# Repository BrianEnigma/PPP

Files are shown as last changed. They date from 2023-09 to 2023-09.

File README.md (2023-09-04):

# The Poltergeist Piano Project (PPP)

## Overview

I'm friends with the owners of a local spooky bar. It's not just a great bar with gourmet food, there's a lot of depth to explore. They've rigged up a bunch of fun gadgetry. There's a mini escape room where dialing a particular phone number plays a prerecorded message and pops open a secret door. There's creepy audio in one of the bathrooms. There's a painting on the wall that jumps out at you as you pass by. There's thunder and lightning in the windows and a flickering fireplace.

One of the owners pointed me to [a YouTube video](https://youtu.be/S7Bd992k368?si=S3JPkRpDpxUU6mec) of a guy who turned his upright piano into a player piano. They have a piano there that people poke at as they pass by to get to the bathroom. He wanted to do something like that to their piano. Turning it into a full player piano was probably out of the question, given time, materials, and tediousness of wiring up each and every one of the 88 keys. But there was definitely a nugget of an idea there.

I proposed a smaller-scale animatronic solution that aligned better with the spooky nature of the bar:

- Three individual low keys wired up.
- A trill (or stinger) of several high keys connected together, to give a bit of a bang-on-the-keys jump scare.
- Some lighting to better draw attention that something's about to happen (and IS happening).
- A distance/proximity sensor to trigger the animation when someone is close-by.
- Tie it all together with a microcontroller that not only controlls all aspects of triggering, animtion, and piano key action, but can also provide holdoff timers so that it doesn't get triggered too terribly often (to the annoyance of bar staff).

## Documentation

[Documentation Here](./Docs)

## License

This project was a commission for a local spooky bar. I am releasing the design files for personal/private/educational use under a [Creative Commons Attribution-NonCommercial-ShareAlike 4.0 International license](https://creativecommons.org/licenses/by-nc-sa/4.0/). You're free to use this project as-is or mutate it into something else if and only if it's for private use in your own home.

If you'd like to use these designs in a public or commercial setting, such as a bar or restaurant, please reach out to me to work out a more specific commercial arrangement.

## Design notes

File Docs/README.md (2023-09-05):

# Poltergeist Piano Project

## Overview

Please read [the top-level readme file](../) for the descriptive overview of this project.

## Bill of Materials (BOM)

- [Adafruit Feather Huzzah, ESP8266](https://www.adafruit.com/product/2821)
    - A similar microcontroller can be used. I just happen to have a ton of these on hand because they're versatile and relatively cheap. This one happens to have a WiFi chip on board, but it's entirely dormant for this project.
- [128x64 OLED screen for Feather](https://www.adafruit.com/product/4650)
    - 100% optional. I like it because it gives me a status display and three buttons that can be used for testing.
- [12V Solenoid](https://www.adafruit.com/product/413) × 4
- [IR Distance Sensor](https://www.adafruit.com/product/1031)
- [Neopixel Strip](https://www.adafruit.com/product/1460), about 53 inches to span the piano
- TIP120 Darlington Transistors × 4
- 1N4004 Diodes × 4
- 1K Ω Resistors × 4
- [7805 5V Linear Voltage Regulator](https://www.adafruit.com/product/2164)
- 12VDC power supply and inline power switch.
- Assorted miscellanea. Wires, solder, heat-shrink tubing, terminal blocks, etc.

## Schematic

The [schematic (pdf link)](schematic.pdf) is fairly straightforward. The [KiCad](https://www.kicad.org) source lives in [the KiCad project folder](../KiCad/). Each of the solenoids is a copy/paste job, joining together a power transistor, resistor, diode, and the solenoid. The Neopixel is wired to a binary data pin. The distance sensor is wired to the one and only ADC pin.

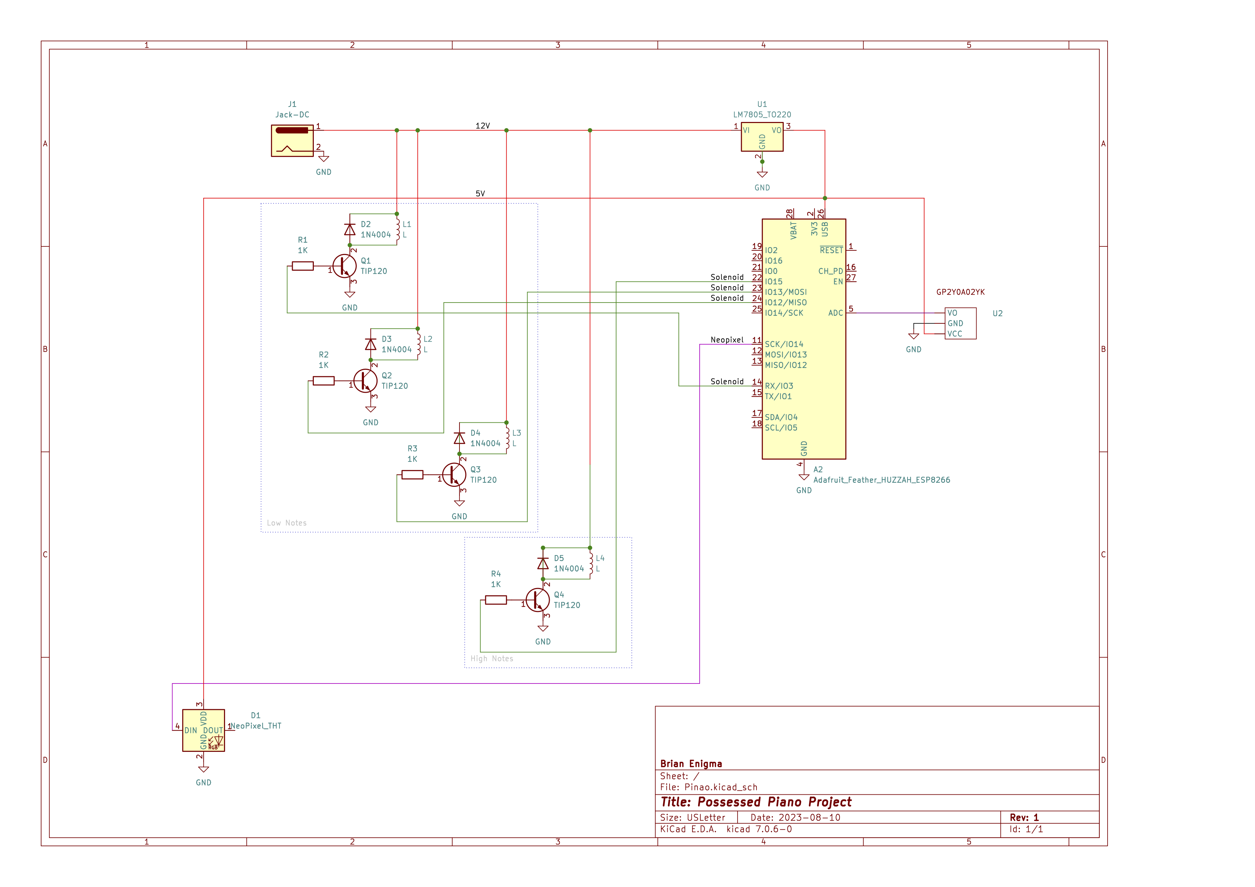
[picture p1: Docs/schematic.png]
schematic


It's worth noting that the pin number that KiCan assigns to the Feather Huzzah microcontroller are not intuitive. They don't match the pin numbers silk-screened onto the board. Nor do they match the internal pin numbers of the ESP8266:

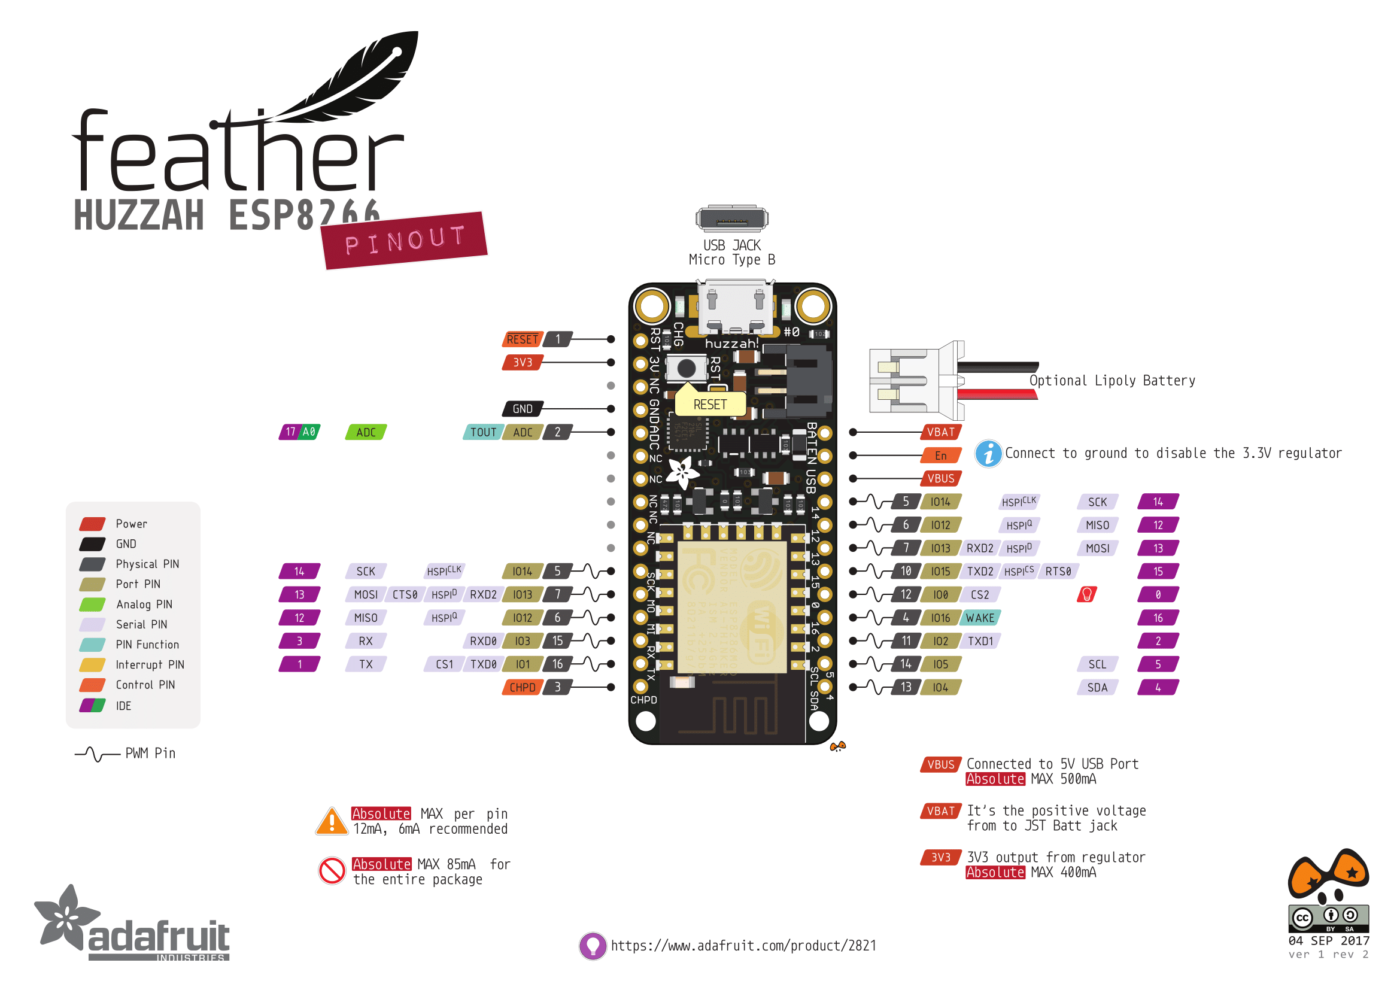
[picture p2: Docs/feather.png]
Feather Huzzah


The numbers in KiCad, instead, count around the outside of the board, treating it like a regular IC chip. For example, looking at the above pinout, KiCad labels “pin 1” as the reset, “pin 2” is the 3.3V line, “pin 3” is the not-connected pin, etc.

## Main-Board Assembly

This is a custom layout on a protoboard.

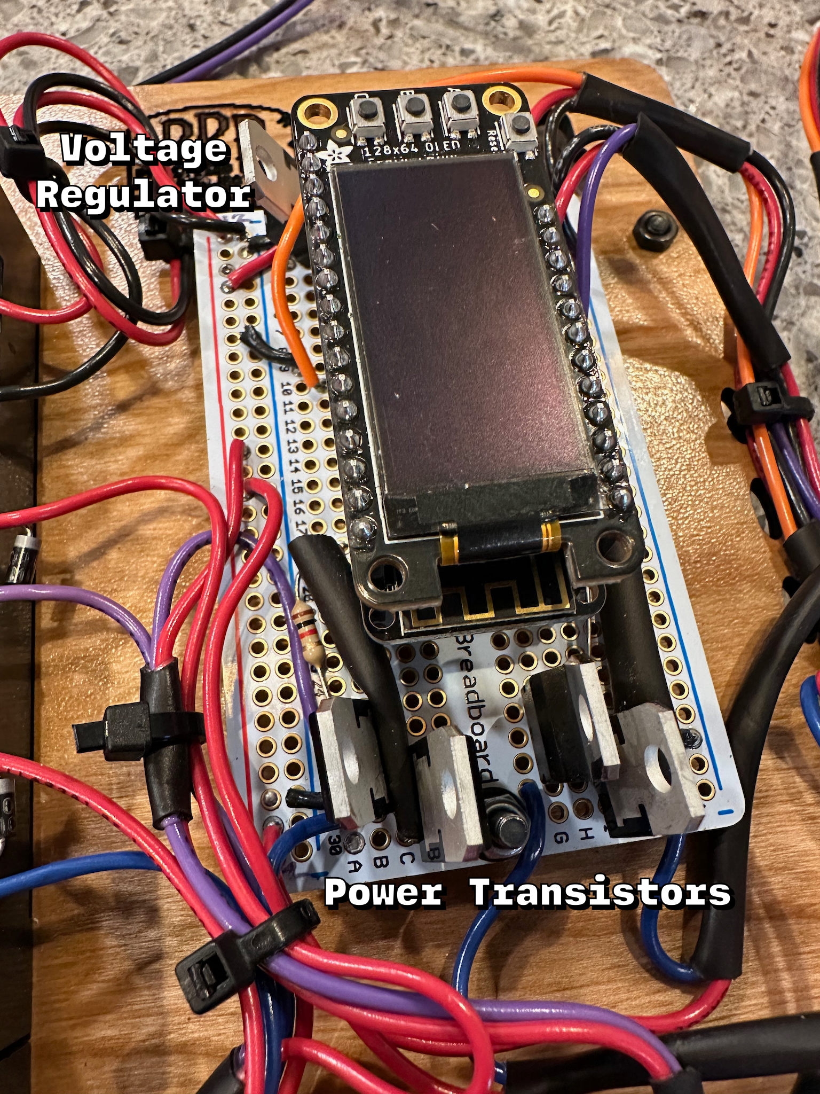
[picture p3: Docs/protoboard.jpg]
protoboard


That protoboard is then attached to a wood backboard that can be mounted. It interfaces with all the remote devices and sensor through screw-down terminal blocks. The lase file for the wood backboard is in [the Laser project folder](../Laser/).

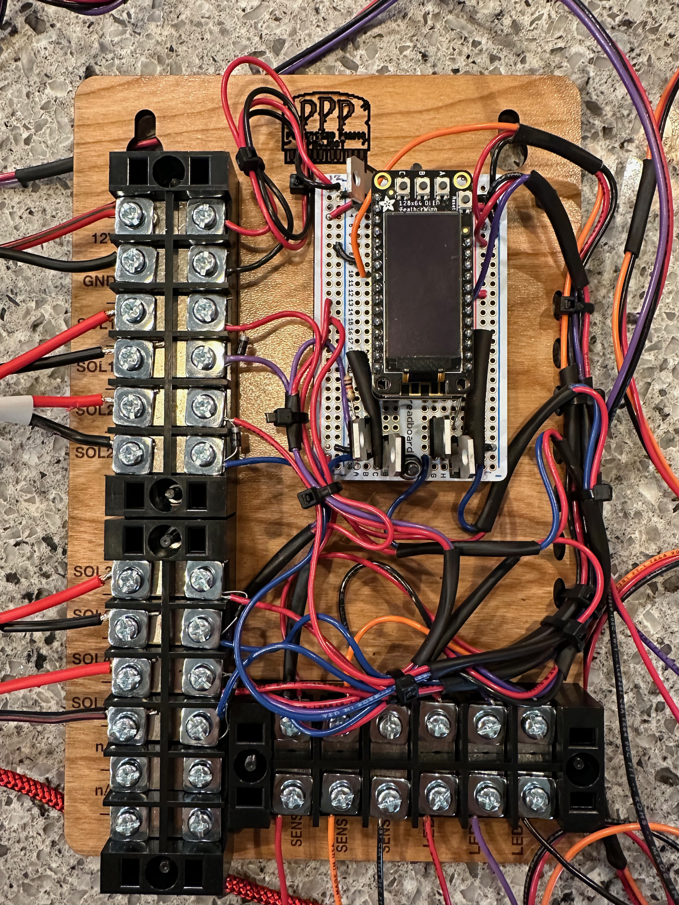
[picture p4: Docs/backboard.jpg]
backboard


Both the Feather microcontroller and the OLED carrier board are attached via pin socket. Either/or can be easily replaced without needing to solder.

## Device/Sensor Assembly

- The solenoids are basic — there are two wires and, because they are simply electromagnetic coils, they are not polarized. They are physically labeled on the solenoid, the hookup wire, and the terminal blocks (as well as in code) 1..4:
    - Solenoid 1: low note
    - Solenoid 2: lower note
    - Solenoid 3: lowest note
    - Solenoid 4: high trill/stinger
- The Neeopixel strip has power, ground, and a data line.
- The proximity/distance sensor has power, ground, and an analog sense line.
- The power plug supplies 12VDC to the mainboard, which gets divided into a 12VDC rail and a 5VDC rail.

All are wired into the labeled terminal blocks. The terminal blocks for the solenoids, on the mainboard side, have protective diodes screwed in along side the hookup wires.

The solenoids are mounted into 3D-printed brackets. These are printed in ABS (the same plastic as LEGO bricks) for strength. They are attached by 6mm M3 metric screws. The bracket files can be found in [the Brackets project folder](../Brackets/).

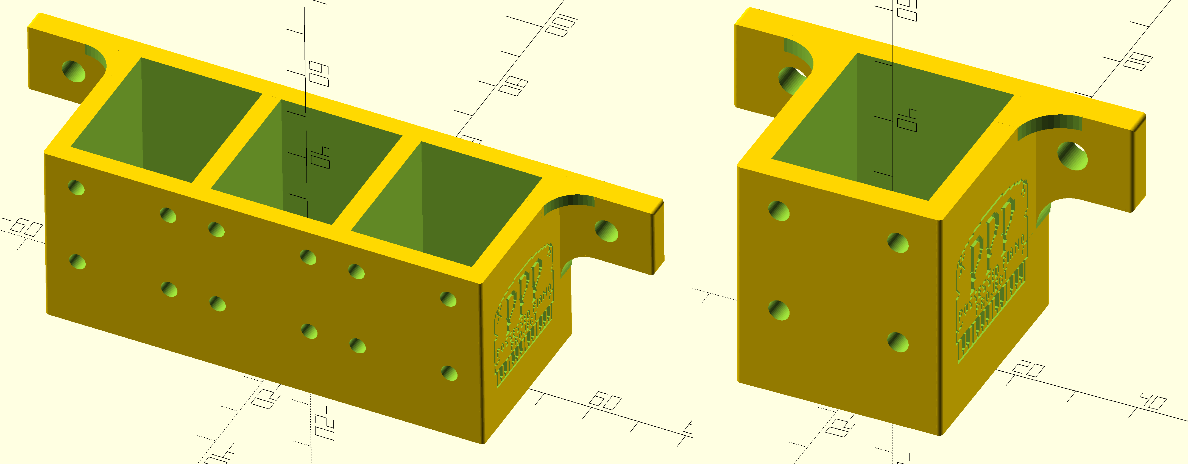
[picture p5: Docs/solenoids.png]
solenoid brackets


_(The above two solenoid images are not to scale between each other. Every cubbyhole is for the same size solenoid.)_

The power plug mount is also printed in ABS and lives in that same folder.

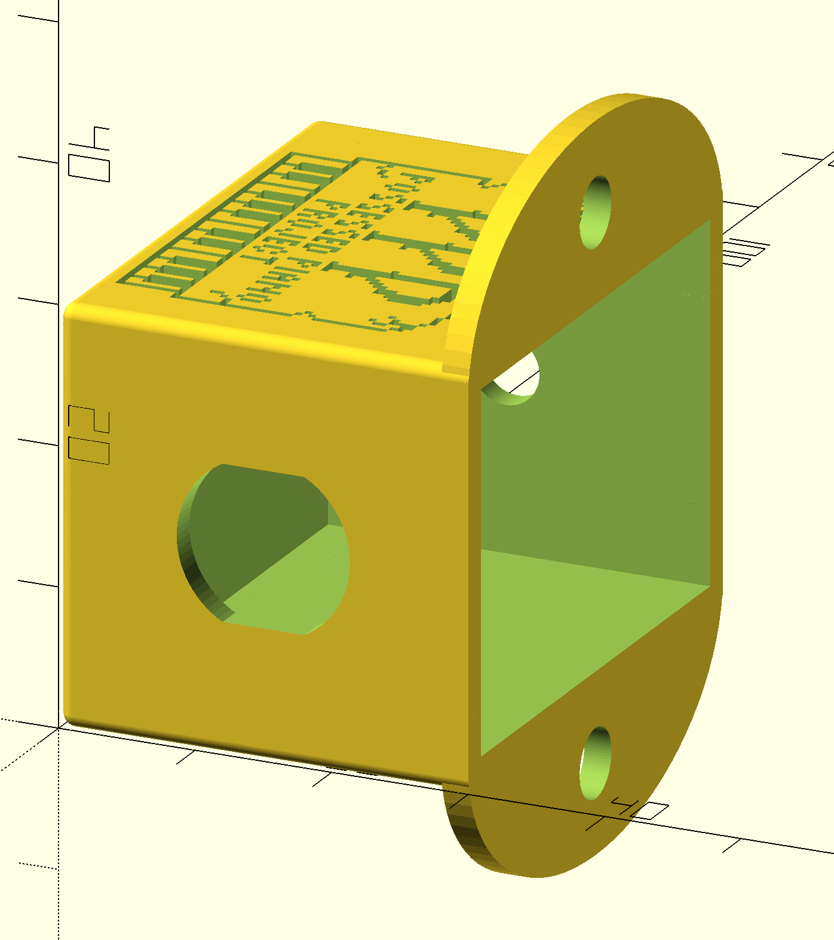
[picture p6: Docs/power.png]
power bracket


## Test Code

There are assorted test/bringup code projects in [the Bringup project folder](../Bringup/). These were used during hardware development and assembly to test out individual circuits and components.

## Production Code

### IDE Setup / Prerequisites

Code is compiled and uploaded through the Arduino IDE. [This can be downloaded from the Arduino site](https://www.arduino.cc/en/software) for Windows, macOS, or Linux. Once the IDE is installed, you'll have to launch it and use its features to install the dependencies required for the microcontroller, display, and LED strip. Adafruit has great guides for installation:

- [Feather Huzzah ESP 8266 toolchain](https://learn.adafruit.com/adafruit-feather-huzzah-esp8266/using-arduino-ide)
- [OLED board library](https://learn.adafruit.com/adafruit-128x64-oled-featherwing/arduino-code)
- [Neopixel library](https://learn.adafruit.com/adafruit-neopixel-uberguide/arduino-library-installation)

New code is uploaded through the micro USB port on the Feather board (it's the board behind the board carrying the OLED screen). Connecting can be a little tight because of the mounting screw for the white protoboard. But there's some give here because the microcontroller is in a socket and can be lifted up slightly.

### The Code

The code performs the following operations:

- At power-up, accidentally, one of the low piano key solenoids is briefly activated. This is a hardware accident (see bugs).
- A holdoff timer of 10 seconds (`POST_BOOT_HOLDOFF_TIMER`) starts counting down. This lets you be near the piano without immediately triggering the animation. Like in _Alien,_ this is a “minimum time to reach safe distance.” This can be bypassed with the “A” button on the display board.
- It waits for the proximity sensor to trigger. The trigger point is `ANALOG_THRESHOLD`, but the sensor I used is a little far-sighted. It's basically either “you're really far away” or “holy crap, you're within 3 feet.” So this threshold is a little bit meaningless.
- Once it detects someone is nearby, it:
    - There's a 1-in-10 (`HIGH_HIT_RANDOM`) chance of triggering the short single-flash, single-high-key-slam animation.
    - Otherwise it triggers the three low key animation.
- It enters a holdoff timer that lasts a random number of minutes between 25 (`HOLDOFF_MIN_TIME_MINUTES`) and 45 (`HOLDOFF_MAX_TIME_MINUTES`).

To help with debugging:

- Any holdoff timer (the power-up one or the between-animations one) can be skipped by hitting the “A” button.
- The between-animations holdoff can also be skipped and immediately go to a specific animation by hitting “C” (low-note animation) or “B” (high-note animation). This allows for testing the hardware installation.

The monospaced name above are constants that can be tweaked in the source and then re-uploaded into the microcontroller.

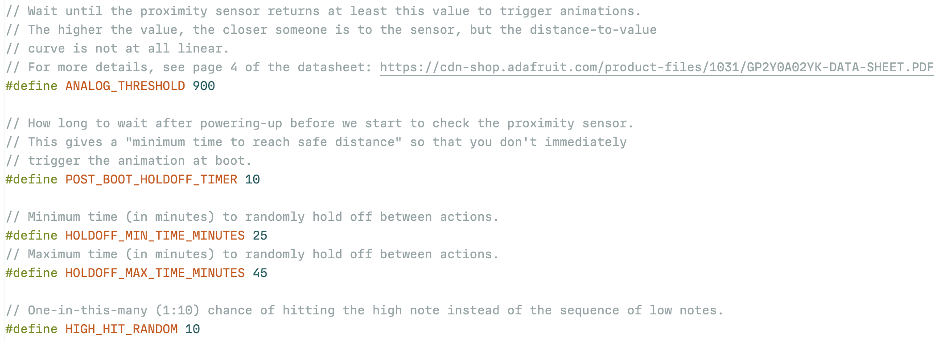
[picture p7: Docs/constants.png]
constants


## Bugs

At power-up, there appears to be a power spike on the Solenoid 1 pin. This appears to be some state the mictrocontroller gets into before any user code is executed. This makes it tough to fix without a big redesign of the circuit. Practically speaking, this means that when powering up the mainboard, one of the low notes gets briefly hit.

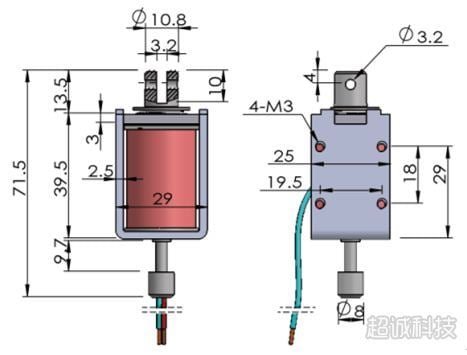
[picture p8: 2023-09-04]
Brackets/large_solenoid_mechanical_schematic.jpg

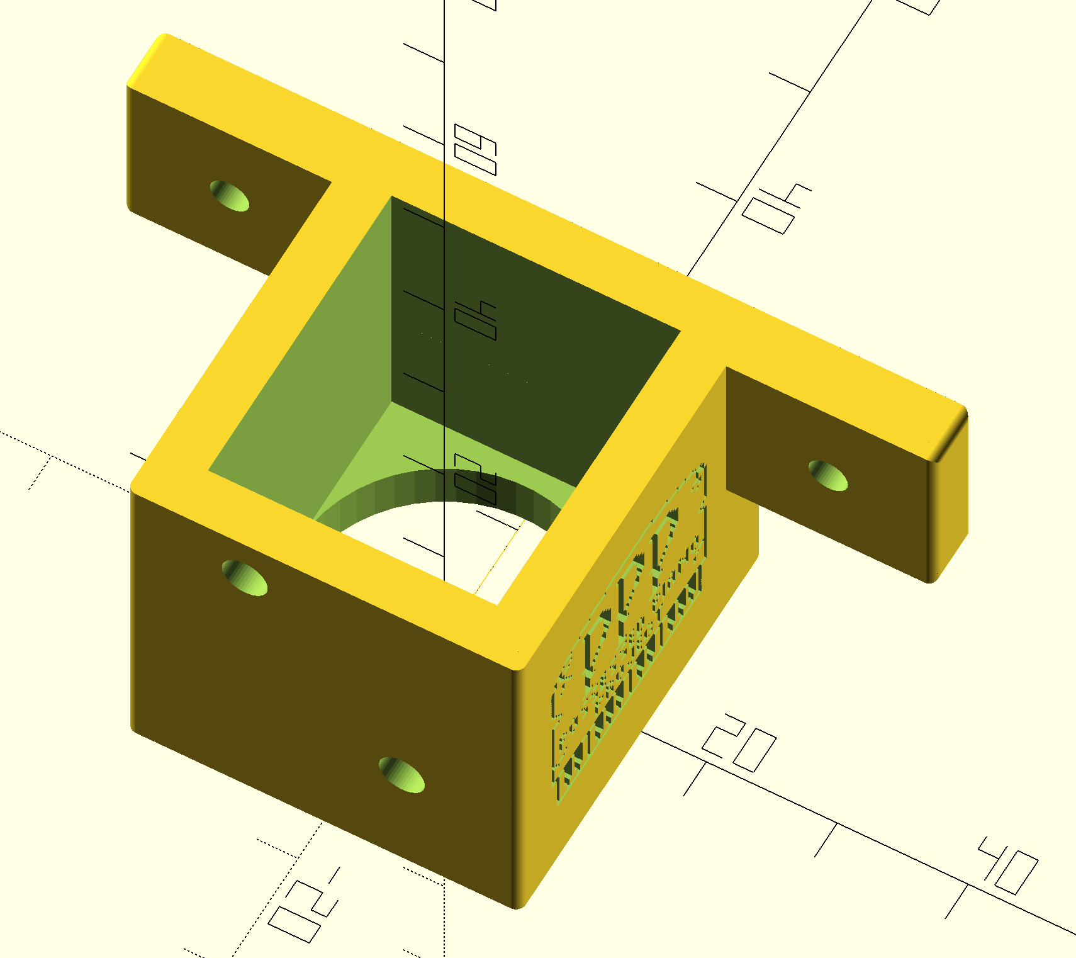
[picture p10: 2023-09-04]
Brackets/small_solenoid_bracket_single-render.png

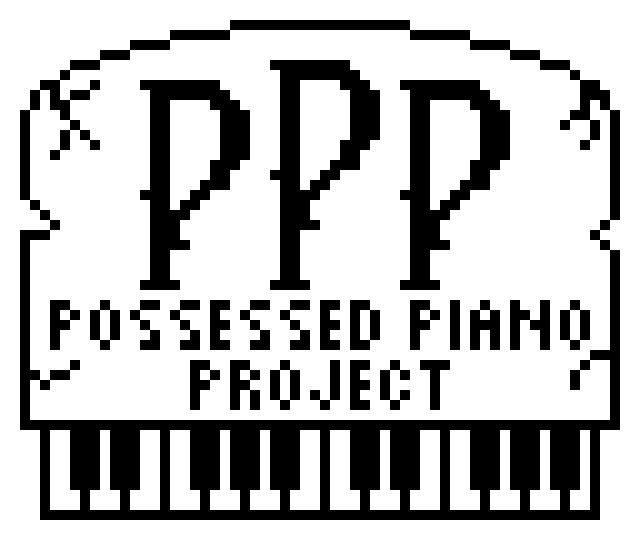
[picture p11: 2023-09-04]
Pixelart/headstone_transparent.png

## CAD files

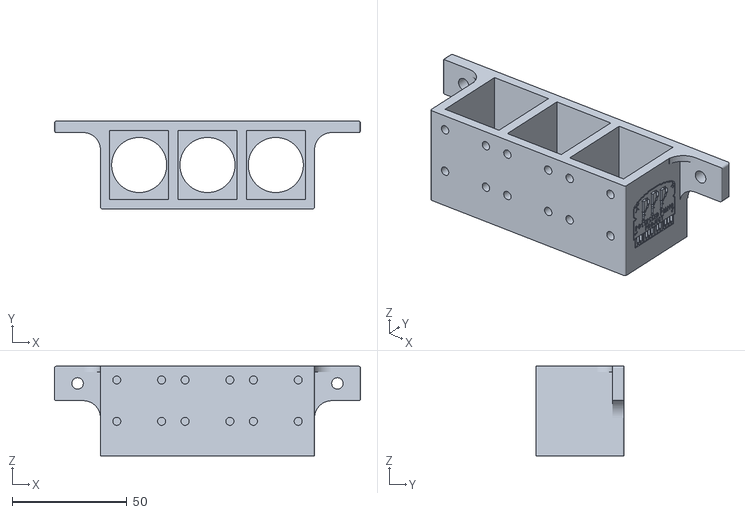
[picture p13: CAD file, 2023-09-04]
Brackets/large_solenoid_bracket_triple.stl
133.2 x 38.2 x 39.0

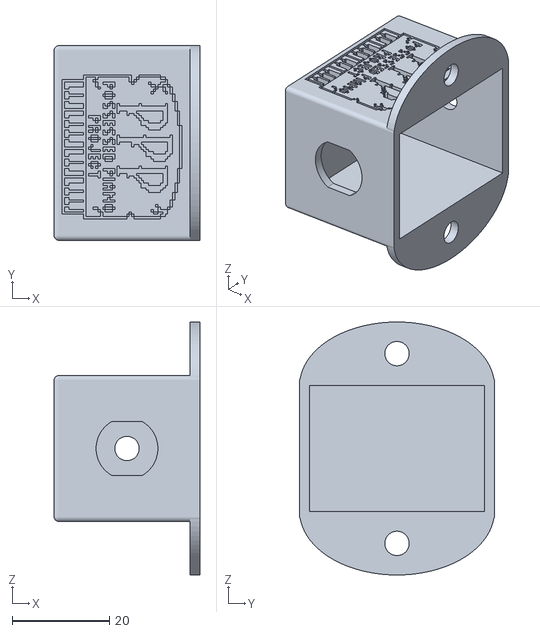
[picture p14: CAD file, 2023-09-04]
Brackets/power_bracket.stl
30.0 x 40.0 x 52.0

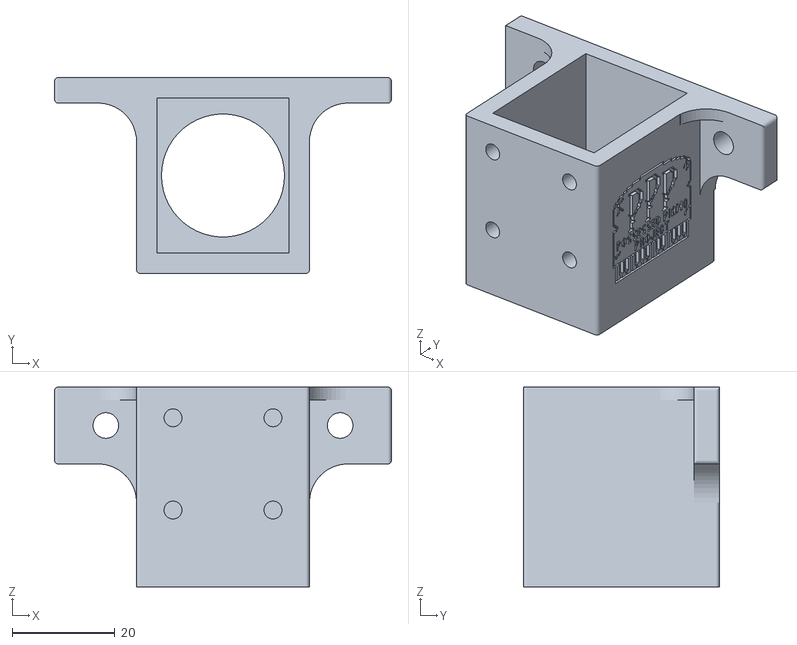
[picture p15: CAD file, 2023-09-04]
Brackets/large_solenoid_bracket_single.stl
65.8 x 38.2 x 39.0

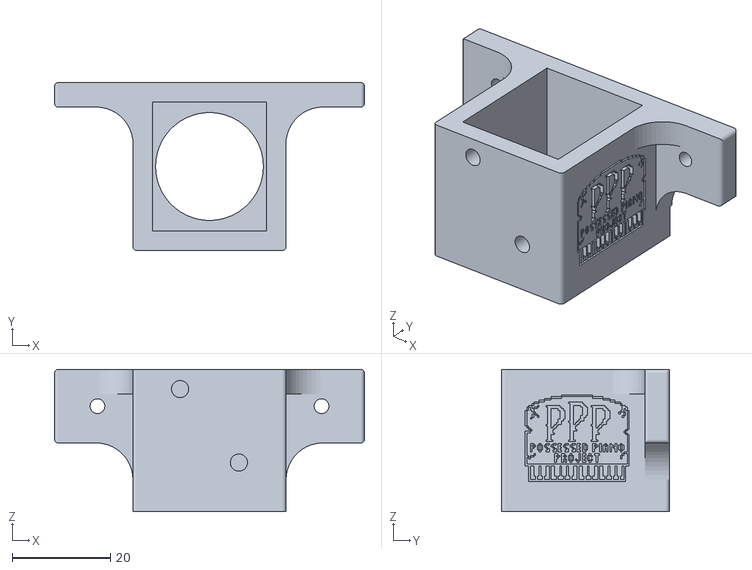
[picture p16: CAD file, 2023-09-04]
Brackets/small_solenoid_bracket_single.stl
63.2 x 34.2 x 29.0

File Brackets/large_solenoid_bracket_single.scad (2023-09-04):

include <BOSL/shapes.scad>
use <BOSL/shapes.scad>

DETAIL = 50;
TOLERANCE = 0.25;
WALL_WIDTH = 4;
FILLET = 0.75;

SOLENOID_WIDTH = 25.5 + TOLERANCE;
SOLENOID_HEIGHT = 30 + TOLERANCE;
SOLENOID_DEPTH = 35;
SOLENOID_OPENING_DIAMETER = 24;

SOLENOID_SCREW_HOLE_OFFSET_X = (19.5 / 2);
SOLENOID_SCREW_HOLE_OFFSET_Y1 = 11;
SOLENOID_SCREW_HOLE_OFFSET_Y2 = 29;
SOLENOID_SCREW_HOLE_DIAMETER = 3.5;

BRACKET_WIDTH = SOLENOID_WIDTH + 40;
BRACKET_HEIGHT = 15;
BRACKET_WALL = 5;
BRAKET_SCREW_HOLE_DIAMETER = 5;

module solenoid_body()
{
        translate(v = [0, 0, SOLENOID_DEPTH / 2 + 5 + WALL_WIDTH])
            cube(size = [SOLENOID_WIDTH, SOLENOID_HEIGHT, SOLENOID_DEPTH + 10], center = true);
}

module screw_hole(offset_x, offset_y)
{
    translate(v = [offset_x, 0, offset_y])
        translate(v = [0, 0, WALL_WIDTH])
            rotate(a = [90, 0, 0])
                cylinder(r = SOLENOID_SCREW_HOLE_DIAMETER / 2, h = SOLENOID_HEIGHT, $fn = DETAIL);

}

module main_body()
{
    body_width = SOLENOID_WIDTH + WALL_WIDTH * 2;
    body_height = SOLENOID_HEIGHT + WALL_WIDTH * 2;
    body_depth = SOLENOID_DEPTH + WALL_WIDTH;
    difference()
    {
        // Main body
        translate(v = [0, 0, body_depth / 2])
            cuboid(
                size = [body_width, body_height, body_depth],
                fillet = FILLET,
                edges = EDGES_Z_ALL,
                center = true,
                $fn = DETAIL
                );

        // Hole for solenoid slug
        translate(v = [0, 0, -1])
            cylinder(r = SOLENOID_OPENING_DIAMETER / 2, h = body_depth + 10, $fn = DETAIL);
        // Solenoid body
        solenoid_body();
        // Mounting holes
        screw_hole(     SOLENOID_SCREW_HOLE_OFFSET_X, SOLENOID_SCREW_HOLE_OFFSET_Y1);
        screw_hole(-1 * SOLENOID_SCREW_HOLE_OFFSET_X, SOLENOID_SCREW_HOLE_OFFSET_Y1);
        screw_hole(     SOLENOID_SCREW_HOLE_OFFSET_X, SOLENOID_SCREW_HOLE_OFFSET_Y2);
        screw_hole(-1 * SOLENOID_SCREW_HOLE_OFFSET_X, SOLENOID_SCREW_HOLE_OFFSET_Y2);
    }
}

module bracket1()
{
    difference()
    {
        // Body
        translate(v = [0, SOLENOID_HEIGHT / 2 + WALL_WIDTH + BRACKET_WALL / -2, BRACKET_HEIGHT / -2 + SOLENOID_DEPTH + WALL_WIDTH])
            cuboid(
                size = [BRACKET_WIDTH, BRACKET_WALL, BRACKET_HEIGHT], 
                fillet = FILLET, 
                edges = EDGES_Z_ALL + EDGES_Y_ALL,
                center = true, 
                $fn = DETAIL);
        // Screw holes
        translate(v = [(BRACKET_WIDTH - SOLENOID_WIDTH) / 1.75, SOLENOID_HEIGHT / 2 - 3, BRACKET_HEIGHT / -2 + SOLENOID_DEPTH + WALL_WIDTH])
            rotate(a = [-90, 0, 0])
                cylinder(r = BRAKET_SCREW_HOLE_DIAMETER / 2, h = BRACKET_WALL * 2, $fn = DETAIL);
        translate(v = [(BRACKET_WIDTH - SOLENOID_WIDTH) / -1.75, SOLENOID_HEIGHT / 2 - 3, BRACKET_HEIGHT / -2 + SOLENOID_DEPTH + WALL_WIDTH])
            rotate(a = [-90, 0, 0])
                cylinder(r = BRAKET_SCREW_HOLE_DIAMETER / 2, h = BRACKET_WALL * 2, $fn = DETAIL);
    }
}

module bracket2()
{
    difference()
    {
        translate(v = [0, SOLENOID_HEIGHT / 2 + WALL_WIDTH + BRACKET_WALL / -2, BRACKET_HEIGHT / -4 + SOLENOID_DEPTH + WALL_WIDTH - BRACKET_HEIGHT + 0.01])
            cuboid(
                size = [SOLENOID_WIDTH + WALL_WIDTH * 2 + BRACKET_HEIGHT, BRACKET_WALL, BRACKET_HEIGHT / 2], 
                center = true, 
                $fn = DETAIL);
        // Arches
        translate(v = [SOLENOID_WIDTH / 2 + WALL_WIDTH + BRACKET_HEIGHT / 2, SOLENOID_HEIGHT / 2 + WALL_WIDTH + BRACKET_WALL / 2, BRACKET_HEIGHT / -2 + SOLENOID_DEPTH + WALL_WIDTH - BRACKET_HEIGHT])
            rotate(a = [90, 0, 0])
                cylinder(r = BRACKET_HEIGHT / 2, h = BRACKET_WALL * 2, $fn = DETAIL);
        translate(v = [SOLENOID_WIDTH / -2 - WALL_WIDTH - BRACKET_HEIGHT / 2, SOLENOID_HEIGHT / 2 + WALL_WIDTH + BRACKET_WALL / 2, BRACKET_HEIGHT / -2 + SOLENOID_DEPTH + WALL_WIDTH - BRACKET_HEIGHT])
            rotate(a = [90, 0, 0])
                cylinder(r = BRACKET_HEIGHT / 2, h = BRACKET_WALL * 2, $fn = DETAIL);
    }
}

module bracket3()
{
    difference()
    {
        translate(v = [0, SOLENOID_HEIGHT / 2 + WALL_WIDTH - BRACKET_HEIGHT / 4 - WALL_WIDTH + 0.01, SOLENOID_DEPTH + WALL_WIDTH - BRACKET_WALL / 4])
            cuboid(
                size = [SOLENOID_WIDTH + WALL_WIDTH * 2 + BRACKET_HEIGHT, BRACKET_HEIGHT / 2, BRACKET_WALL /2], 
                center = true, 
                $fn = DETAIL);
        translate(v = [0, BRACKET_HEIGHT / -2, 0])
            translate(v = [SOLENOID_WIDTH / -2 - WALL_WIDTH + BRACKET_HEIGHT / -2, SOLENOID_HEIGHT / 2 + WALL_WIDTH - BRACKET_WALL, SOLENOID_DEPTH + WALL_WIDTH / 2 - BRACKET_WALL])
                cylinder(r = BRACKET_HEIGHT / 2, h = BRACKET_WALL * 2, $fn = DETAIL);
        translate(v = [0, BRACKET_HEIGHT / -2, 0])
            translate(v = [SOLENOID_WIDTH / 2 + WALL_WIDTH + BRACKET_HEIGHT / 2, SOLENOID_HEIGHT / 2 + WALL_WIDTH - BRACKET_WALL, SOLENOID_DEPTH + WALL_WIDTH / 2 - BRACKET_WALL])
                cylinder(r = BRACKET_HEIGHT / 2, h = BRACKET_WALL * 2, $fn = DETAIL);
    }
}

module bracket_all()
{
    difference()
    {
        union()
        {
            bracket1();
            bracket2();
            bracket3();
        }
        solenoid_body();
    }
}

module logo()
{
    translate(v = [0, -2, 8])
        translate(v = [SOLENOID_HEIGHT / 2 + WALL_WIDTH / 2, -13, 0])
            rotate(a = [90, 0, 90])
                linear_extrude(height = 2, center = true, convexity = 10)
                    scale(v = [0.12, 0.12, 0.12])
                        offset(0.01)
                            import("headstone_transparent_vectorized.svg");


    translate(v = [0, -2, 8])
        translate(v = [SOLENOID_HEIGHT / -2 + WALL_WIDTH / -2, 13, 0])
            rotate(a = [90, 0, -90])
                linear_extrude(height = 2, center = true, convexity = 10)
                    scale(v = [0.12, 0.12, 0.12])
                        offset(0.01)
                            import("headstone_transparent_vectorized.svg");
}

module main()
{
    difference()
    {
        union()
        {
            main_body();
            bracket_all();
        }
        logo();
    }
}

mode = 1;

if (1 == mode)
{
    main();
    // To verify the mounting holes:
    /*
    translate(v = [0, 0, WALL_WIDTH])
        translate(v = [0, -20, 0])
            cylinder(h = SOLENOID_SCREW_HOLE_OFFSET_Y1, r = 10);
    translate(v = [0, 0, WALL_WIDTH])
        translate(v = [0, -20, 0])
            cylinder(h = SOLENOID_SCREW_HOLE_OFFSET_Y2, r = 10);
    */
} else if (2 == mode)
{
    union()
    {
        main();
        #solenoid_body();
    }
} else if (3 == mode)
{
    intersection()
    {
        main();
        #solenoid_body();
    }
} else if (4 == mode)
{
    bracket_all();
}

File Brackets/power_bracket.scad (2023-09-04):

include <BOSL/constants.scad>
use <BOSL/shapes.scad>

WIDTH = 30;
HEIGHT = 30;
DEPTH = 40;
WALL = 2;
HOLE = 5;
SCREW_HOLE = 5;

DETAIL = 80;

module powerCutout()
{
	intersection() {
		cylinder(r = 12.7/2, h = 10, $fn = DETAIL);
		cube(size = [30, 11.2, 30], center = true);

	}
}

module shell()
{
	difference() {
		cuboid(size = [WIDTH, DEPTH, HEIGHT], fillet = 1, edges = EDGES_X_ALL + EDGES_LEFT, center = false, $fn = DETAIL);
		translate(v = [WALL, WALL, WALL])
			cube(size = [WIDTH * 2, DEPTH - 2 * WALL, HEIGHT - 2 * WALL]);

	}
}

module bracket()
{
	difference()
	{
		scale(v = [0.65, 1, 1])
			cylinder(r = DEPTH / 2, h = WALL, $fn = DETAIL);
		translate(v = [0, -25, -25])
			cube(size = 50, 50, 50);
		translate(v = [DEPTH / -4 * 0.65, 0, -1])
			cylinder(r = SCREW_HOLE / 2, h = WALL * 2, $fn = DETAIL);
	}
}

module upperBracket()
{
 	translate(v = [WIDTH - WALL, DEPTH / 2, HEIGHT - WALL])
 	rotate(a = [0, 90, 0])
 	bracket();
}

module lowerBracket()
{
 	translate(v = [WIDTH, DEPTH / 2, WALL])
 	rotate(a = [0, -90, 0])
 	bracket();
}

module body()
{
	union() {
		shell();
		upperBracket();
		lowerBracket();
	}
}

module connectorHole()
{
	translate(v = [WIDTH / 2, -5, HEIGHT / 2])
		rotate(a = [-90, 0, 0])
			powerCutout();
}

module wireHole()
{
	translate(v = [WIDTH / 2, DEPTH - 5, HEIGHT / 2])
		rotate(a = [-90, 0, 0])
			cylinder(r = HOLE / 2, h = 10, $fn = DETAIL);

}

module logo()
{
     translate(v = [0, DEPTH - 5, HEIGHT - 0.5])
         rotate(a = [0, 0, -90])
            linear_extrude(height = 2, center = true, convexity = 10)
                scale(v = [0.14, 0.14, 0.1])
                    offset(0.01)
                        import("headstone_transparent_vectorized.svg");
}

difference()
{
	body();
	connectorHole();
	wireHole();
	logo();
}

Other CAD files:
Brackets/large_solenoid_bracket_triple.scad
Brackets/small_solenoid_bracket_single.scad

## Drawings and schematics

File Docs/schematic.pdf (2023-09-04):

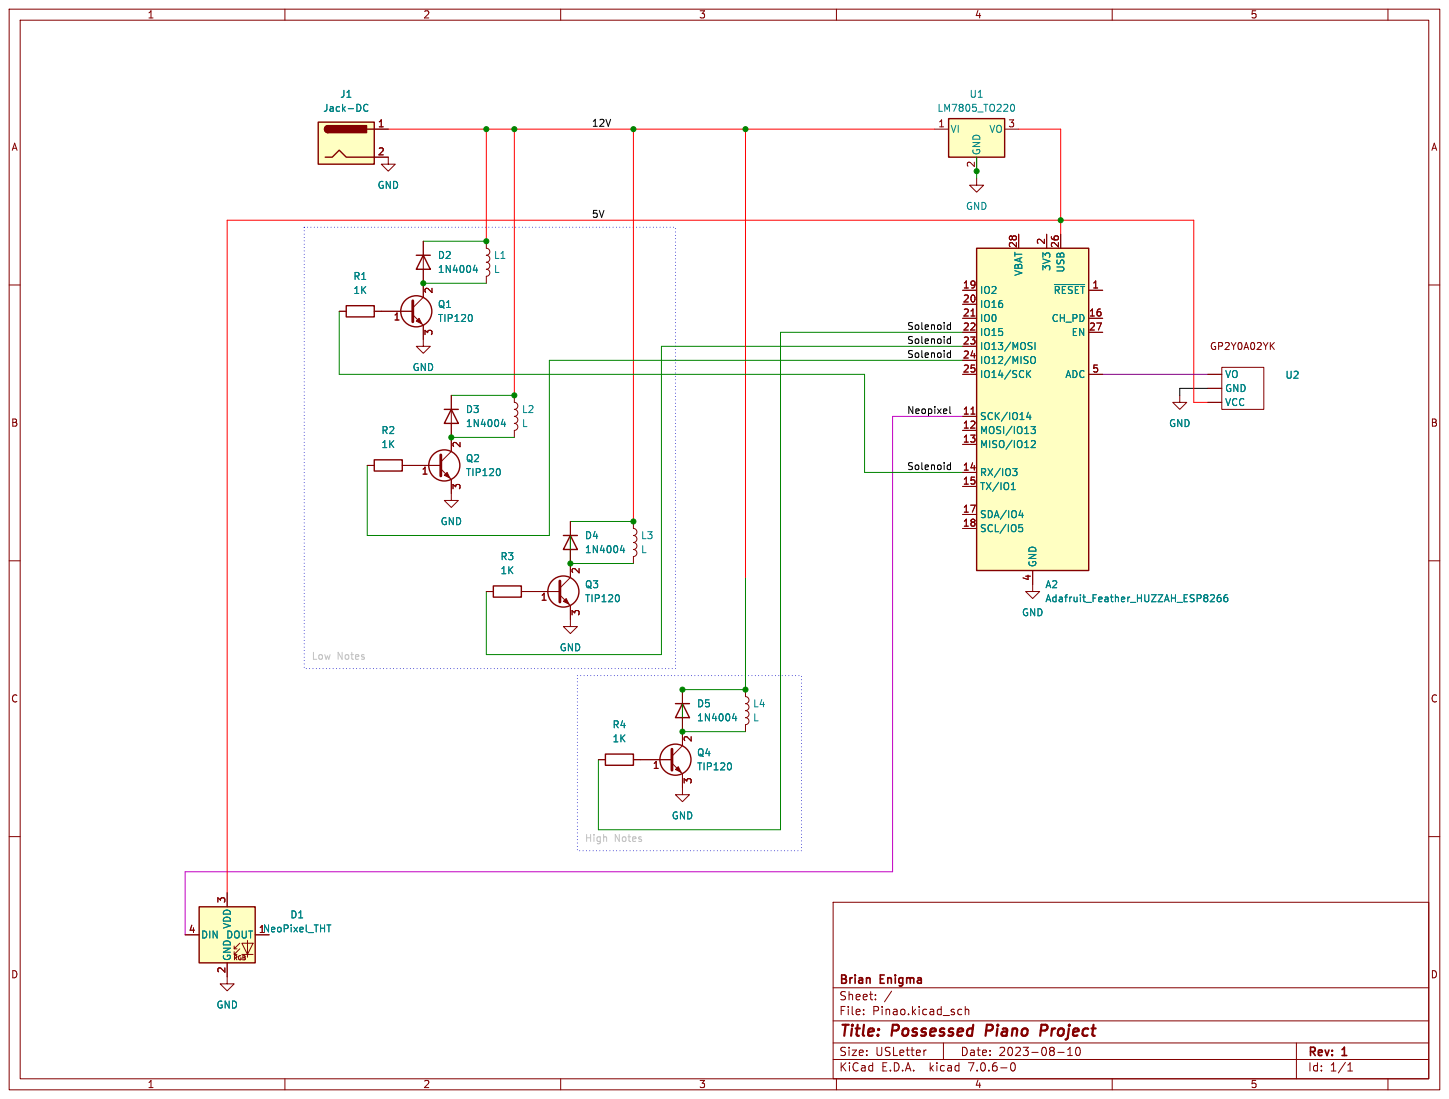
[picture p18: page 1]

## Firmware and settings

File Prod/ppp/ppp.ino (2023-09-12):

#include <SPI.h>
#include <Wire.h>
#include <Adafruit_GFX.h>
#include <Adafruit_SH110X.h>
#include <Adafruit_NeoPixel.h>

// --------------------------------------------------------------------------------
// --- User-Servicible Parts:

// Wait until the proximity sensor returns at least this value to trigger animations.
// The higher the value, the closer someone is to the sensor, but the distance-to-value
// curve is not at all linear. 
// For more details, see page 4 of the datasheet: https://cdn-shop.adafruit.com/product-files/1031/GP2Y0A02YK-DATA-SHEET.PDF
#define ANALOG_THRESHOLD 900

// How long to wait after powering-up before we start to check the proximity sensor.
// This gives a "minimum time to reach safe distance" so that you don't immediately
// trigger the animation at boot.
// This is in seconds.
#define POST_BOOT_HOLDOFF_TIMER 3

// Minimum time (in minutes) to randomly hold off between actions.
#define HOLDOFF_MIN_TIME_MINUTES 10
// Maximum time (in minutes) to randomly hold off between actions.
#define HOLDOFF_MAX_TIME_MINUTES 15

// One-in-this-many (1:10) chance of hitting the high note instead of the sequence of low notes.
#define HIGH_HIT_RANDOM 8

// --------------------------------------------------------------------------------
// Beyond this, thar be dragons. Try not to mess with any of this unless you really
// know what you're doing.

//#define INCLUDE_SERIAL

#define SOLENOID_PIN_1 3
#define SOLENOID_PIN_2 12
#define SOLENOID_PIN_3 13
#define SOLENOID_PIN_4 15

#define NEOPIXEL_PIN 14
#define NUMPIXELS 40
Adafruit_NeoPixel pixels(NUMPIXELS, NEOPIXEL_PIN, NEO_GRB + NEO_KHZ800);

Adafruit_SH1107 display = Adafruit_SH1107(64, 128, &Wire);
#define BUTTON_A  0
#define BUTTON_B 16
#define BUTTON_C  2

// 1-bit pixel art representation of the tombstone logo.
const uint8_t LOGO[] = {0x00, 0x00, 0x00, 0x00, 0x00, 0x00, 0x00, 0x00, 
0x00, 0x00, 0x00, 0x00, 0x00, 0x00, 0x00, 0x00, 
0x00, 0x00, 0x01, 0xFF, 0xFF, 0x80, 0x00, 0x00, 
0x00, 0x00, 0x7E, 0x00, 0x00, 0x7E, 0x00, 0x00, 
0x00, 0x07, 0x80, 0x00, 0x00, 0x01, 0xE0, 0x00, 
0x00, 0x38, 0x00, 0x00, 0x00, 0x00, 0x1C, 0x00, 
0x01, 0xC0, 0x00, 0x1F, 0xE0, 0x00, 0x03, 0x80, 
0x02, 0x00, 0x00, 0x0F, 0xF0, 0x00, 0x00, 0x40, 
0x0C, 0x43, 0xFC, 0x0C, 0x38, 0xFF, 0x00, 0x30, 
0x15, 0x81, 0xFE, 0x0C, 0x1C, 0x7F, 0x80, 0x38, 
0x16, 0x01, 0x87, 0x0C, 0x1C, 0x61, 0xC0, 0x28, 
0x22, 0x01, 0x83, 0x8C, 0x1C, 0x60, 0xE0, 0x64, 
0x21, 0x01, 0x83, 0x8C, 0x1C, 0x60, 0xE0, 0x94, 
0x22, 0x81, 0x83, 0x8C, 0x1C, 0x60, 0xE0, 0x14, 
0x22, 0x41, 0x83, 0x8C, 0x38, 0x60, 0xE0, 0x24, 
0x24, 0x01, 0x83, 0x8C, 0x30, 0x60, 0xE0, 0x04, 
0x20, 0x01, 0x87, 0x0C, 0x70, 0x61, 0xC0, 0x04, 
0x20, 0x01, 0x86, 0x1C, 0xC0, 0x61, 0x80, 0x04, 
0x20, 0x01, 0x8E, 0x0D, 0x80, 0x63, 0x80, 0x04, 
0x20, 0x03, 0x98, 0x0F, 0x00, 0xE6, 0x00, 0x04, 
0x10, 0x01, 0xB0, 0x0E, 0x00, 0x6C, 0x00, 0x04, 
0x08, 0x01, 0xE0, 0x0E, 0x00, 0x78, 0x00, 0x04, 
0x04, 0x01, 0xC0, 0x0F, 0x00, 0x70, 0x00, 0x08, 
0x38, 0x01, 0xC0, 0x0C, 0x00, 0x70, 0x00, 0x10, 
0x20, 0x01, 0xE0, 0x0C, 0x00, 0x78, 0x00, 0x08, 
0x20, 0x01, 0x80, 0x0C, 0x00, 0x60, 0x00, 0x04, 
0x20, 0x01, 0x80, 0x0C, 0x00, 0x60, 0x00, 0x04, 
0x20, 0x01, 0x80, 0x0C, 0x00, 0x60, 0x00, 0x04, 
0x20, 0x03, 0xC0, 0x1E, 0x00, 0xF0, 0x00, 0x04, 
0x20, 0x00, 0x00, 0x00, 0x00, 0x00, 0x00, 0x04, 
0x26, 0x23, 0x36, 0x66, 0xD8, 0x64, 0x92, 0x44, 
0x25, 0x54, 0x44, 0x88, 0x94, 0x55, 0x5A, 0xA4, 
0x26, 0x52, 0x26, 0x44, 0xD4, 0x65, 0xD6, 0xA4, 
0x24, 0x51, 0x14, 0x22, 0x94, 0x45, 0x52, 0xA4, 
0x24, 0x23, 0x36, 0x66, 0xD8, 0x45, 0x52, 0x44, 
0x20, 0x00, 0x00, 0x00, 0x00, 0x00, 0x00, 0x1C, 
0x21, 0x00, 0x19, 0x88, 0x59, 0x38, 0x00, 0x24, 
0x36, 0x00, 0x15, 0x54, 0x52, 0x90, 0x00, 0x44, 
0x28, 0x00, 0x19, 0x94, 0x5A, 0x10, 0x00, 0x44, 
0x20, 0x00, 0x11, 0x55, 0x52, 0x90, 0x00, 0x04, 
0x20, 0x00, 0x11, 0x48, 0x99, 0x10, 0x00, 0x04, 
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
const unsigned int LOGO_SIZE = sizeof(LOGO) / sizeof(LOGO[0]);

char g_forcedTrigger = 0;

// Light up all of the LEDs the same color.
void lightAll(unsigned char red, unsigned char green, unsigned char blue, unsigned int wait)
{
    uint32_t color = pixels.Color(red, green, blue);
    for (int i = 0; i < NUMPIXELS; i++)
    {
        pixels.setPixelColor(i, color);
    }
    pixels.show();
    delay(wait);
}

// Turn off the LED strip.
void off()
{
    for (int i = 0; i < NUMPIXELS; i++)
    {
        pixels.setPixelColor(i, 0x000000);
    }
    pixels.show();
}

// Load the logo onto the screen and display it.
// Note that this doesn't first clear the screen.
void loadLogo()
{
    unsigned int x = 0;
    unsigned int y = 0;
    for (unsigned int byte = 0; byte < LOGO_SIZE; byte++)
    {
        for (unsigned int bit = 0; bit < 8; bit++)
        {
            display.drawPixel(y, 63 - x, (LOGO[byte] >> (7 - bit)) & 0x01);
            x++;
        }
        if (x >= 64)
        {
            x = 0;
            y++;
        }
    }
    display.display();
    display.setTextSize(1);
    display.setTextColor(SH110X_WHITE);
    display.setCursor(54,0);
}

void holdoffTimer(const char *message, int seconds)
{
    bool earlyAbort = false;
    display.clearDisplay();
    display.setRotation(1);
    loadLogo();
    display.setCursor(54,0);
    display.print(message);
    display.setCursor(54, 10);
    display.print("A to skip");
    while (seconds > 0 && !earlyAbort)
    {
        int displayMinutes = seconds / 60;
        int displaySeconds = seconds % 60;
        display.fillRect(54, 20, 128 - 54, 64 - 20, 0x00);
        display.setCursor(54, 20);
        display.setTextSize(2);
        display.print(displayMinutes);
        display.print(":");
        if (displaySeconds < 10)
            display.print("0");
        display.print(displaySeconds);
        seconds--;
        display.display();
        for (int repeat = 0; repeat < 10 && !earlyAbort; repeat++)
        {
            if (!digitalRead(BUTTON_A))
            {
                earlyAbort = true;
            }
            delay(100);
        }
        if (seconds % 20 == 0) // Double-check the LEDs are off every so often.
            off();
    }
    display.clearDisplay();
    display.setRotation(1);
    loadLogo();
    display.display();
    delay(500);
}

void setup() 
{
    // Set up all the pins early to help prevent glitches on the line due to floating pins
    // while the other components are initializing.
    pinMode(SOLENOID_PIN_1, OUTPUT);
    pinMode(SOLENOID_PIN_2, OUTPUT);
    pinMode(SOLENOID_PIN_3, OUTPUT);
    pinMode(SOLENOID_PIN_4, OUTPUT);
    digitalWrite(SOLENOID_PIN_1, LOW);
    digitalWrite(SOLENOID_PIN_2, LOW);
    digitalWrite(SOLENOID_PIN_3, LOW);
    digitalWrite(SOLENOID_PIN_4, LOW);

#ifdef INCLIDE_SERIAL
    Serial.begin(115200);
#endif

#if defined(__AVR_ATtiny85__) && (F_CPU == 16000000)
    clock_prescale_set(clock_div_1);
#endif
    pixels.begin(); // INITIALIZE NeoPixel strip object (REQUIRED)
    pixels.setBrightness(100);
    off();
    pixels.show();

#ifdef INCLIDE_SERIAL
    Serial.println("Piano Controller Booting Up...");
#endif
    delay(250); // wait for the OLED to power up
    display.begin(0x3C, true); // Address 0x3C default

#ifdef INCLIDE_SERIAL
    Serial.println("OLED started");
#endif

    display.clearDisplay();
    display.setRotation(1);
    loadLogo();
    display.display();
    delay(1000);

    // text display tests
    display.setTextSize(1);
    display.setTextColor(SH110X_WHITE);
    display.setCursor(54,0);
    display.print("Test Mode");
    display.setCursor(54,8);
    display.print("A=LED Strip");
    display.setCursor(54,16);
    display.print("B=Sol 1,2,3");
    display.setCursor(54,24);
    display.print("C=Sol 4");

    display.display(); // actually display all of the above

    // This is the only analog pin, and it's not left floating, so is reading actively from the distance
    // sensor. Here, we just hope the distance sensor is providing values that are "random enough" to
    // give us a decent seed.
    randomSeed(analogRead(A0));

    // Give some time to "reach minimum safe distance" before prox sensing kicks in.
    holdoffTimer("StartupDelay", POST_BOOT_HOLDOFF_TIMER);
}

void waitForProx()
{
    off();
    display.clearDisplay();
    display.setRotation(1);
    loadLogo();
    display.setCursor(54,0);
    display.print("Waiting for");
    display.setCursor(54,10);
    display.print("Prox...");
    display.setCursor(54, 55);
    display.print("C/B = force");
    display.display();
    while (true)
    {
        //int value = map(analogRead(A0), 0, 1023, 0, 255);
        int value = analogRead(A0);
        display.fillRect(54, 20, 128 - 54, 16, 0x00);
        display.setTextSize(2);
        display.setCursor(54,20);
        display.print("v:");
        display.print(value);
        display.display();
        if (value >= ANALOG_THRESHOLD)
            break;
        if (!digitalRead(BUTTON_C))
        {
            g_forcedTrigger = 1;
            break;
        } else if (!digitalRead(BUTTON_B))
        {
            g_forcedTrigger = 2;
            break;
        }
        delay(250);        
    }
    display.fillRect(54, 0, 128 - 54, 64, 0x00);
    display.setTextSize(2);
    display.setCursor(54,8);
    display.display();
    display.print("Prox Trig");
}

void bangLow()
{
    const unsigned char low = 128;
    const unsigned int delayStart = 3;
    const unsigned int delayEnd = 10;
    const unsigned char lightningHigh = 192;
    const unsigned int delayLightning = 2;
#ifdef INCLIDE_SERIAL
    Serial.println("Testing LEDs");
#endif
    // Fade up red.
    for (int i = 0; i < low; i++)
        lightAll(i, 0, 0, delayStart);
    delay(1000);
    // Pulse
    for (int repeat = 0; repeat < 3; repeat++)
    {
#if 0
        // Activate each key in sequence.
        switch (repeat)
        {
            case 0: digitalWrite(SOLENOID_PIN_1, HIGH); break;
            case 1: digitalWrite(SOLENOID_PIN_2, HIGH); break;
            case 2: digitalWrite(SOLENOID_PIN_3, HIGH); break;
        }
#else        
        // First key stays down. Hit second, then third. Only two keys every held down at once.
        switch (repeat)
        {
            case 0: 
                digitalWrite(SOLENOID_PIN_1, HIGH); 
                break;
            case 1: 
                digitalWrite(SOLENOID_PIN_2, HIGH); 
                break;
            case 2: 
                digitalWrite(SOLENOID_PIN_2, LOW); 
                digitalWrite(SOLENOID_PIN_3, HIGH); 
                break;
        }
#endif
        // Lightning strike
        for (int i = lightningHigh; i > 0; i--)
            lightAll(i > low ? i : low, i, i, delayLightning);
#if 0
        delay(1000);
#else
        delay(500);
        digitalWrite(SOLENOID_PIN_2, LOW);
        delay(500);
        if (repeat == 2)
            delay(1000);
#endif        
    }
    // Let go of all keys.
    digitalWrite(SOLENOID_PIN_1, LOW);
    digitalWrite(SOLENOID_PIN_2, LOW);
    digitalWrite(SOLENOID_PIN_3, LOW);
    // Fade to black
    for (int i = low; i >= 0; i--)
        lightAll(i, 0, 0, delayEnd);
    // Ensure we're off.
    off();
#ifdef INCLIDE_SERIAL
    Serial.println("Done");
#endif
}

void bangHigh()
{
    const int lightningHigh = 192;
    const int lightningLow = 0;
    const int delayLightning = 2;
#ifdef INCLIDE_SERIAL
    Serial.println("Banging High Solenoid");
#endif
    // Activate key
    digitalWrite(SOLENOID_PIN_4, HIGH);
    // Single lightning flash.
    for (int i = lightningHigh; i > 0; i--)
        lightAll(i, i, i, delayLightning);
    delay(250);
    // Deactivate key
    digitalWrite(SOLENOID_PIN_4, LOW);
    off();
    delay(1000);
#ifdef INCLIDE_SERIAL
    Serial.println("Done");
#endif
}

void loop() 
{
    waitForProx();
    if (g_forcedTrigger == 2 || (((int) random(0, HIGH_HIT_RANDOM - 1)) == 0))
    {
        bangHigh();
    } else {
        bangLow();
    }
    g_forcedTrigger = 0;
    // Delay between 25 and 45 minutes...
    holdoffTimer("HoldoffTimer", 60 * random(HOLDOFF_MIN_TIME_MINUTES, HOLDOFF_MAX_TIME_MINUTES));
    delay(10);
    yield();
}

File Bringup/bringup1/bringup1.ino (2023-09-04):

#include <Adafruit_NeoPixel.h>

#ifdef __AVR__
 #include <avr/power.h> // Required for 16 MHz Adafruit Trinket
#endif

#define LED_PIN    13
#define LED_COUNT 40
Adafruit_NeoPixel strip(LED_COUNT, LED_PIN, NEO_GRB + NEO_KHZ800);

void setup() {
    #if defined(__AVR_ATtiny85__) && (F_CPU == 16000000)
        clock_prescale_set(clock_div_1);
    #endif
    strip.begin();
    strip.show();
    strip.setBrightness(100);
    Serial.begin(38400);
}

void lightAll(unsigned char red, unsigned char green, unsigned char blue, unsigned int wait)
{
    const unsigned char skip = 1;
    uint32_t color = strip.Color(red, green, blue);
    for (int i = 0; i < strip.numPixels(); i += skip)
    {
        strip.setPixelColor(i, color);
    }
    strip.show();
    delay(wait);
}

void off()
{
    for (int i = 0; i < strip.numPixels(); i++)
    {
        strip.setPixelColor(i, 0x000000);
    }
    strip.show();
}

void redPulse()
{
    const unsigned char low = 96;
    const unsigned char high = 255;
    const unsigned int delayStart = 4;
    const unsigned int delayPulse = 8;
    // Fade up
    for (int i = 0; i < low; i++)
        lightAll(i, 0, 0, delayStart);
    // Pulse
    for (int repeat = 0; repeat < 6; repeat++)
    {
        for (int i = low; i < high; i++)
            lightAll(i, 0, 0, delayPulse);
        for (int i = high; i > low; i--)
            lightAll(i, 0, 0, delayPulse);
    }
    // Fade out
    for (int i = low; i >= 0; i--)
        lightAll(i, 0, 0, delayStart);
    off();
}

void greenPulse()
{
    const unsigned char low = 96;
    const unsigned char high = 255;
    const unsigned int delayStart = 4;
    const unsigned int delayPulse = 8;
    // Fade up
    for (int i = 0; i < low; i++)
        lightAll(0, i, 0, delayStart);
    // Pulse
    for (int repeat = 0; repeat < 6; repeat++)
    {
        for (int i = low; i < high; i++)
            lightAll(0, i, 0, delayPulse);
        for (int i = high; i > low; i--)
            lightAll(0, i, 0, delayPulse);
    }
    // Fade out
    for (int i = low; i >= 0; i--)
        lightAll(0, i, 0, delayStart);
    off();
}

void redWithLightning()
{
    const unsigned char low = 128;
    const unsigned int delayStart = 10;
    const unsigned char lightningHigh = 192;
    const unsigned int delayLightning = 2;
    // Fade up
    for (int i = 0; i < low; i++)
        lightAll(i, 0, 0, delayStart);
    delay(1000);
    // Pulse
    for (int repeat = 0; repeat < 3; repeat++)
    {
        for (int i = lightningHigh; i > 0; i--)
            lightAll(i > low ? i : low, i, i, delayLightning);
        delay(1000);
    }
    // Fade out
    for (int i = low; i >= 0; i--)
        lightAll(i, 0, 0, delayStart);
    off();

}

void redWithRedLightning()
{
    const unsigned char low = 128;
    const unsigned int delayStart = 10;
    const unsigned char lightningHigh = 255;
    const unsigned int delayLightning = 2;
    // Fade up
    for (int i = 0; i < low; i++)
        lightAll(i, 0, 0, delayStart);
    delay(1000);
    // Pulse
    for (int repeat = 0; repeat < 3; repeat++)
    {
        for (int i = lightningHigh; i > low; i--)
            lightAll(i, 0, 0, delayLightning);
        delay(1000);
    }
    // Fade out
    for (int i = low; i >= 0; i--)
        lightAll(i, 0, 0, delayStart);
    off();

}

void lightning()
{
    const unsigned char bright = 255;
    const unsigned int wait = 2;
    for (int repeat = 0; repeat < 3; repeat++)
    {
        for (int i = bright; i > 0; i--)
            lightAll(i, i, i, wait);
        off();
        delay(1000);
    }
}

void rgbTest()
{
    const uint32_t colors[] = {
        strip.Color(255, 0, 0),
        strip.Color(0, 255, 0),
        strip.Color(0, 0, 255),
        strip.Color(255, 255, 255),
        strip.Color(0, 0, 0)
    };
    const unsigned int colorCount = sizeof(colors) / sizeof(colors[0]);
    const int wipeDelay = 20;
    const int interWipeDelay = 750;
    for (int color = 0; color < colorCount; color++)
    {
        for (int i = 0; i < strip.numPixels(); i += 1)
        {
            strip.setPixelColor(i, colors[color]);
            strip.show();
            delay(wipeDelay);
        }
        delay(interWipeDelay);
    }
}

void threeRedHits()
{
    int positions[] = {30, 20, 10};
    const unsigned int positionCount = sizeof(positions) / sizeof(positions[0]);
    const unsigned int wipeDelay = 10;
    const unsigned int interWipeDelay = 1000;
    const int fadeMultiplier = 20;
    for (int position = 0; position < positionCount; position++)
    {
        for (int color = 0; color < 2; color++)
        {   
            uint32_t theColor = strip.Color(0, 0, 0);
            for (int i = 0; i < strip.numPixels(); i++)
            {
                if (color == 0)
                    if (255 - fadeMultiplier * i > 0)
                        theColor = strip.Color(255 - fadeMultiplier * i, 0, 0);
                int left = positions[position] - i;
                int right = positions[position] + i;
                if (left >= 0)
                    strip.setPixelColor(left, theColor);
                if (right < strip.numPixels())
                    strip.setPixelColor(right, theColor);
                strip.show();
                delay(wipeDelay);
            }
        }
        delay(interWipeDelay);
    }
}

unsigned int previousMenuSelection = 0;
unsigned int doMenu()
{
    unsigned int result = 0;
    do
    {
        Serial.println("\n\n\n\n\n\n\n\n\n\n");
        Serial.println("MENU");
        Serial.println("~~~~");
        Serial.println("1.  Red Pulse");
        Serial.println("2.  Green Pulse");
        Serial.println("3.  Red With Lightning");
        Serial.println("4.  Lightning");
        Serial.println("5.  Red With Red Lightning");
        Serial.println("6.  Three Red Hits");
        Serial.println("99. RGB Test");
        do {
        } while (!Serial.available());
        String entry = Serial.readStringUntil('\n');
        if (entry.length() == 0)
        {
            result = previousMenuSelection;
        } else {
            result = entry.toInt();
        }
    } while ((result == 0 || result > 6) && result != 99);
    previousMenuSelection = result;
    return result;
}

void loop() {
    unsigned int value = doMenu();
    Serial.print("GOT VALUE: ");
    Serial.println(value);
    switch(value)
    {
        case 1: redPulse(); break;
        case 2: greenPulse(); break;
        case 3: redWithLightning(); break;
        case 4: lightning(); break;
        case 5: redWithRedLightning(); break;
        case 6: threeRedHits(); break;
        case 99: rgbTest(); break;
    }

}
